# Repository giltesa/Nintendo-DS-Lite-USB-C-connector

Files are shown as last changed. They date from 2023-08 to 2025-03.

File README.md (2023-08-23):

# Nintendo DS Lite: USB-C connector

This is a special USB-C connector witch can be used to be directly soldered on the Nintendo DS Lite mainboard.

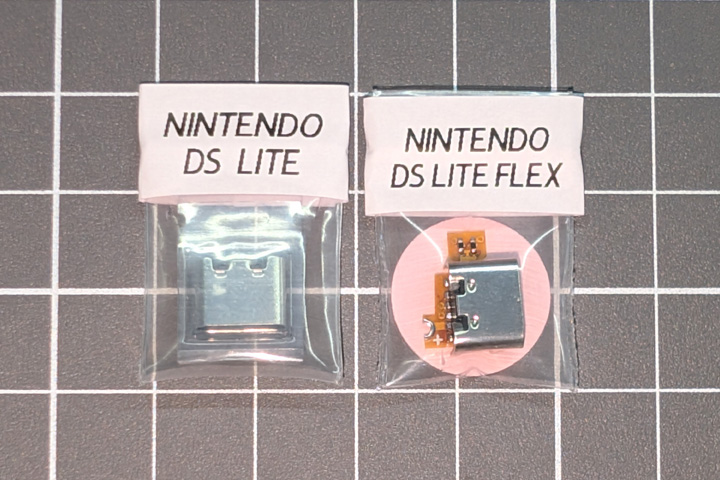
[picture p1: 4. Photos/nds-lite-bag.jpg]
Nintendo DS Lite: USB-C connector


## Note

This repo is only to host the PDF guide, there aren't design files.

## Would you like it?

[Nintendo DS Lite: USB-C connector](https://shop.giltesa.com/product/nintendo-ds-lite-usb-c-connector/)

## More

- [giltesa.com](https://giltesa.com "giltesa.com")
- [twitter.com](https://twitter.com/giltesa "twitter.com")

## License

This project is licensed under a **Creative Commons** license:
**[Attribution-NonCommercial-ShareAlike 4.0 International (CC BY-NC-SA 4.0) ](https://creativecommons.org/licenses/by-nc-sa/4.0/)**

Check the [LICENSE.md](LICENSE.md) for more information.

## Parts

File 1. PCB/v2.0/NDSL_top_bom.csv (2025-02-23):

Comment | Designator | Footprint | LCSC Part #
5.1K | R1 R2 | R0402 | C25905
USBC | J1 | USB-C_6P_SMD_NDSL | C668623

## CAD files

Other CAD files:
2. Renders, 3D models/NDS-LITE-FLEX.skp

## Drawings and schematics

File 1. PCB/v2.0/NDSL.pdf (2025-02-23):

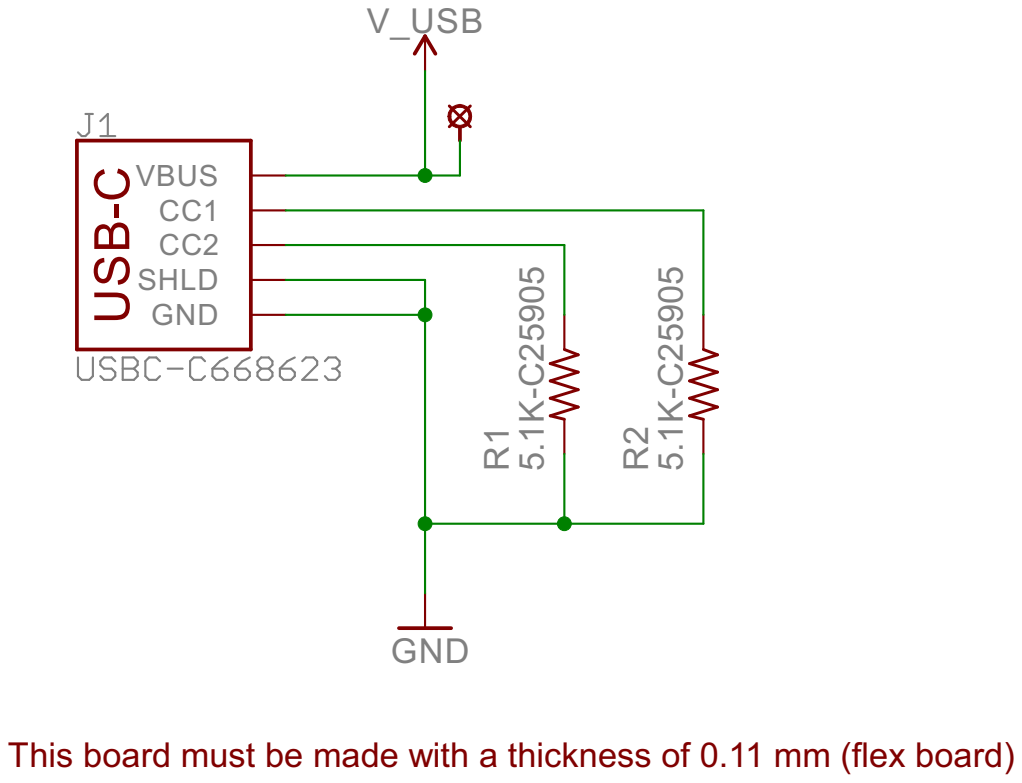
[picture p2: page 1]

This board must be made with a thickness of 0.11 mm (flex board)

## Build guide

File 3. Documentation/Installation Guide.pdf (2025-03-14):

# USB-C MOD for Nintendo DS Lite

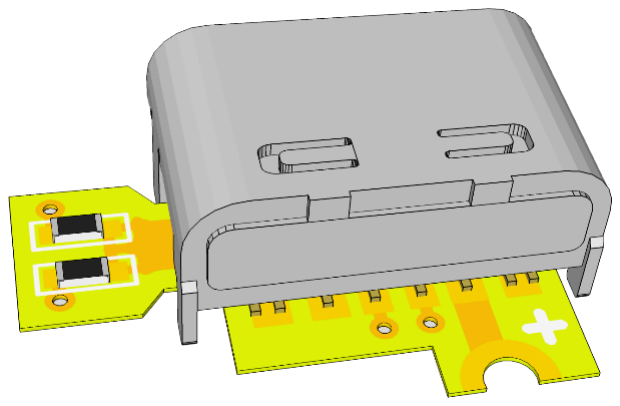
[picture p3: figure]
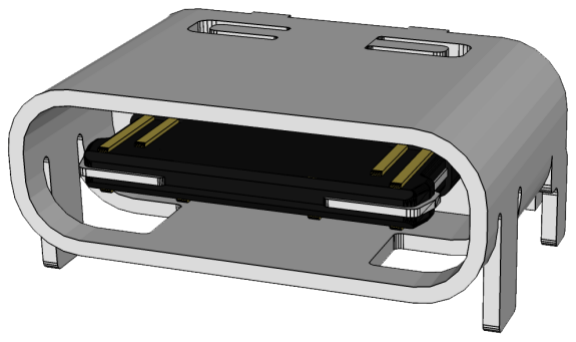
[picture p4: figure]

Connector version | board version

### PRODUCT

HTTPS://SHOP.GILTESA.COM/PRODUCT/NINTENDO-DS-LITE-USB-C-CONNECTOR HTTPS://SHOP.GILTESA.COM/PRODUCT/NINTENDO-DS-LITE-USB-C-KIT

# PLEASE READ THROUGH THESE INSTRUCTIONS

ENTIRELY BEFORE ATTEMPTING TO INSTALL.

# WARNING: IF YOU ARE NOT COMFORTABLE WITH SOLDERING, OR PERFORMING ANY STEP IN THIS

GUIDE, DO NOT PERFORM THE INSTALL YOURSELF.

# FIND SOMEONE WHO IS COMFORTABLE TO DO IT FOR

YOU.

INDEX

# Description

This product is a special USB-C connector which can be used to be directly soldered on the Nintendo DS Lite mainboard.

# FEATURES

- The USB-C connector match 100% perfect with the original connector shape and legs polarity.
- Charging your Nintendo DS Lite with:
- USB power banks
- USB-A chargers
- USB-C chargers*
- USB-C PD chargers (normal speed, not fast)*
- USB-A to USB-C cables
- USB-C to USB-C cables*

* Only the board version.

# INCLUDED

- USB-C connector or USB-C board (depending on the version you chose)

# Recommended / REQUIRED (NOT INCLUDED)

- Tri-wing and Phillips screwdriver
- Soldering iron
- Tin
- Desoldering pump
- Desoldering mesh
- Isopropyl alcohol

# NOTES

The connector version is not compatible with USB-C to USB-C cables; only standard USB to USB-C cables work.

The board version, however, is compatible with any cable or charger.

# Test the board!

Before starting the installation, you should test the board. If it doesn’t work contact me for a replacement (https://shop.giltesa.com/refund-policy/) (all boards are fully tested, but they may damage during the shipping, we try to package them as better as possible), if it works, go ahead with the installation.

Connect the power from your USB charger to the USB-C connector on the board. Then, with a multimeter in voltage measurement mode, check for a 5V reading. If that's the case, continue with the installation.

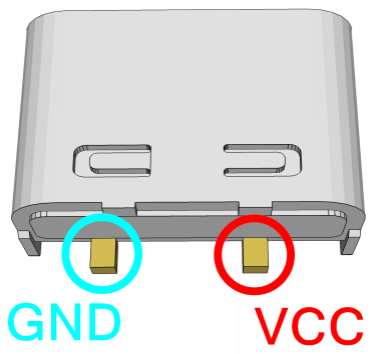
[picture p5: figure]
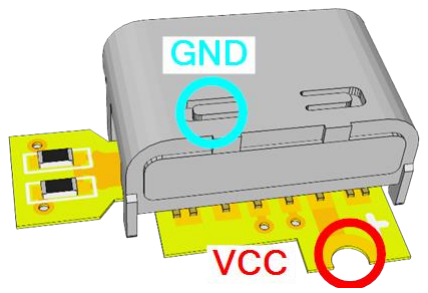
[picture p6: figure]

# INSTALLATION STEPS

## Pre installation Steps

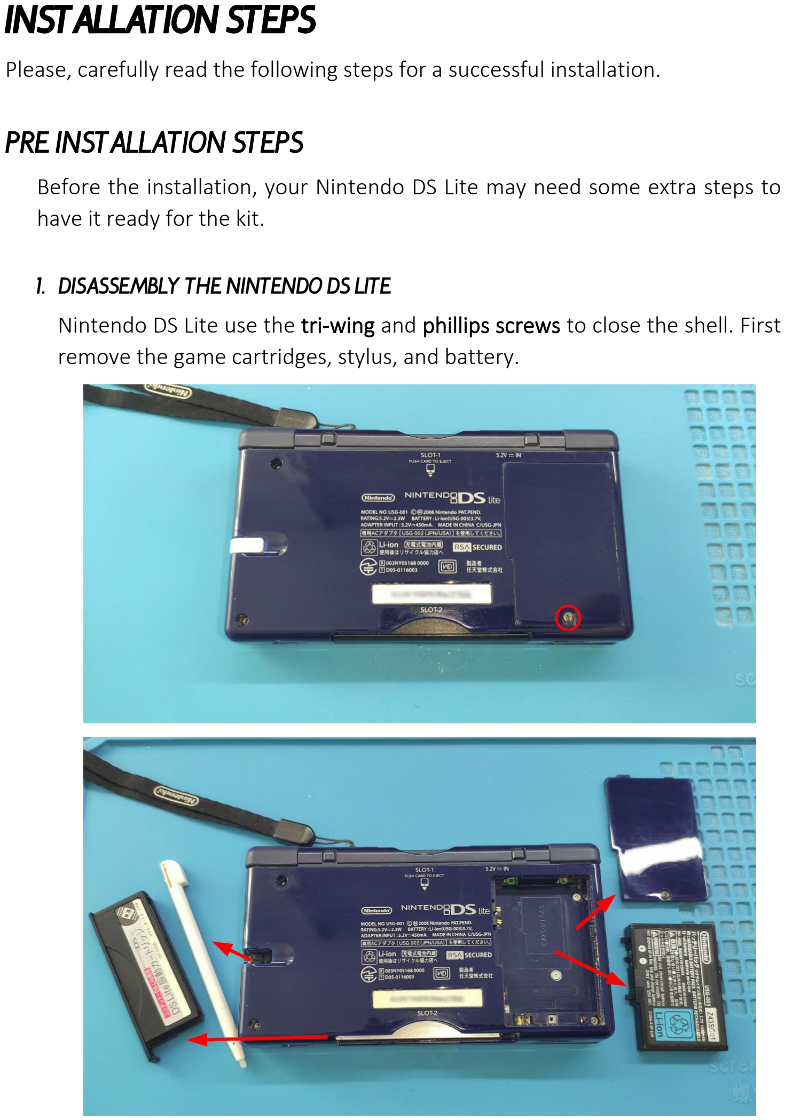
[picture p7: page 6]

Please, carefully read the following steps for a successful installation.

Before the installation, your Nintendo DS Lite may need some extra steps to have it ready for the kit.

1. Disassembly the Nintendo DS Lite

Nintendo DS Lite use the tri-wing and phillips screws to close the shell. First remove the game cartridges, stylus, and battery.

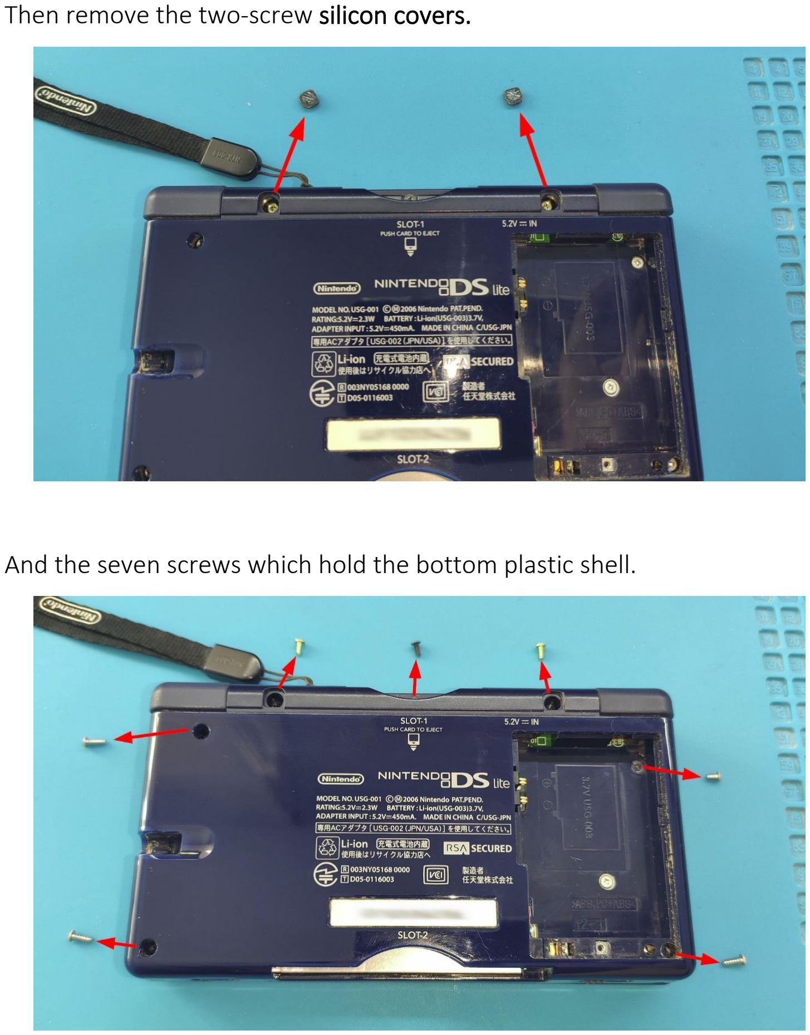
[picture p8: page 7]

Then remove the two-screw silicon covers.

And the seven screws which hold the bottom plastic shell.

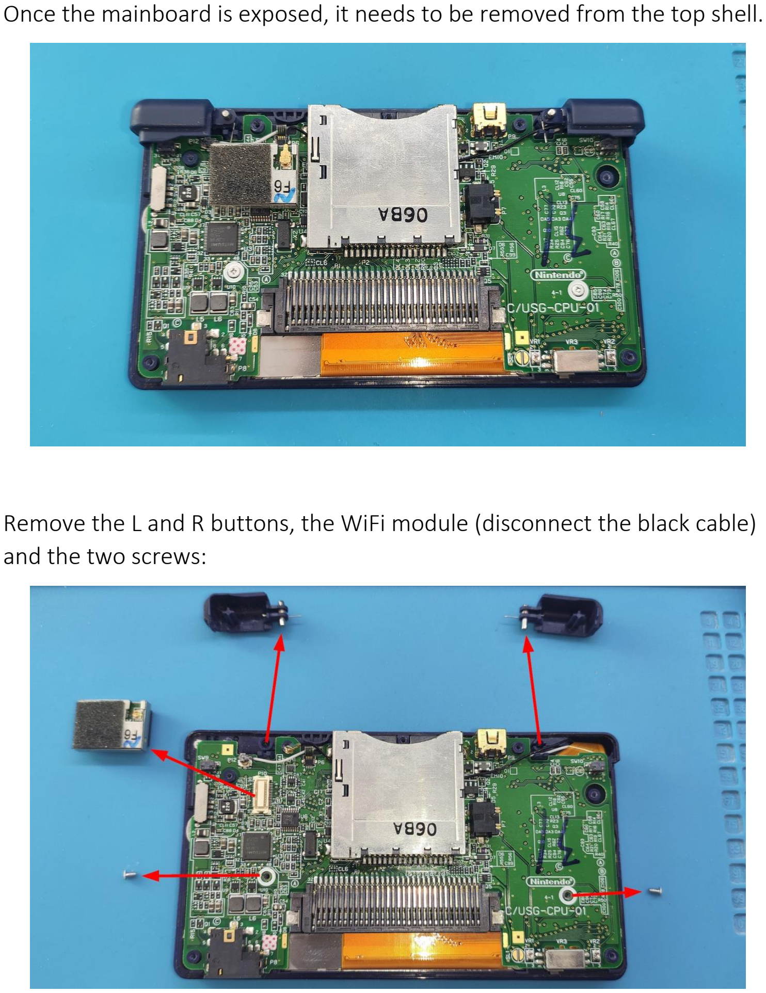
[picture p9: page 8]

Once the mainboard is exposed, it needs to be removed from the top shell.

Remove the L and R buttons, the WiFi module (disconnect the black cable) and the two screws:

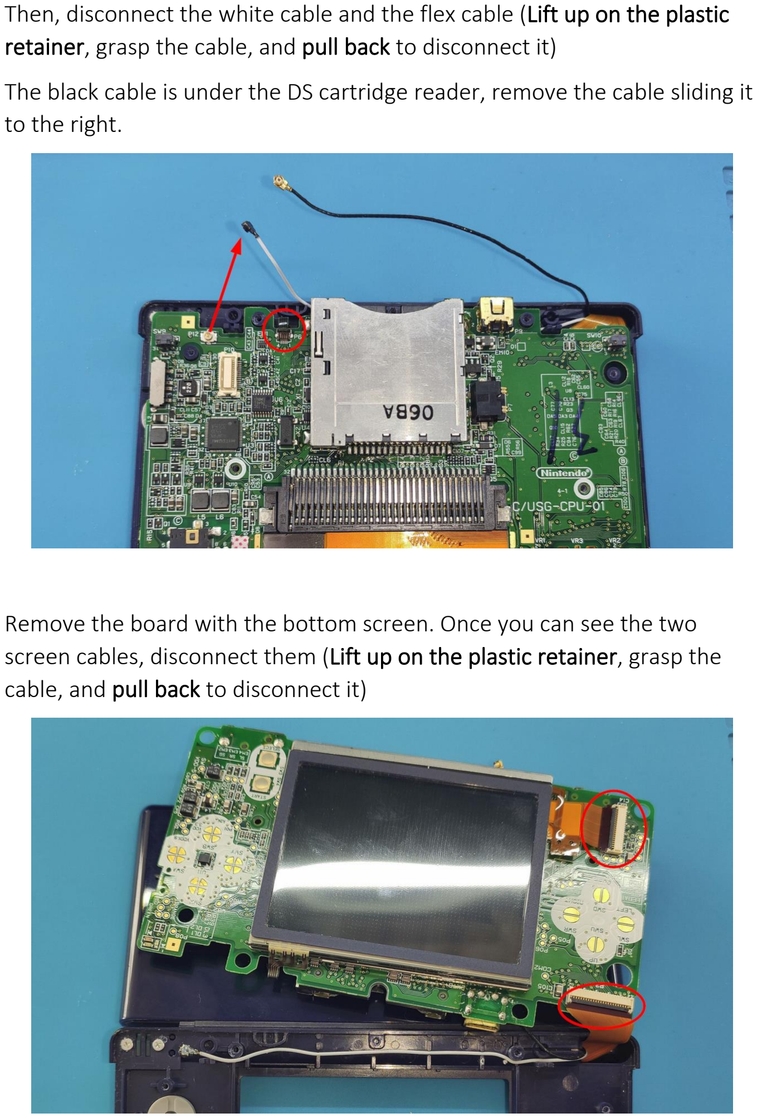
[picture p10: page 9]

Then, disconnect the white cable and the flex cable (Lift up on the plastic retainer, grasp the cable, and pull back to disconnect it)

The black cable is under the DS cartridge reader, remove the cable sliding it to the right.

Remove the board with the bottom screen. Once you can see the two screen cables, disconnect them (Lift up on the plastic retainer, grasp the cable, and pull back to disconnect it)

## installation Steps

1. Protect the nearest components

Use Kapton tape to protect and avoid any damage to the electronic components that are next to the connector.

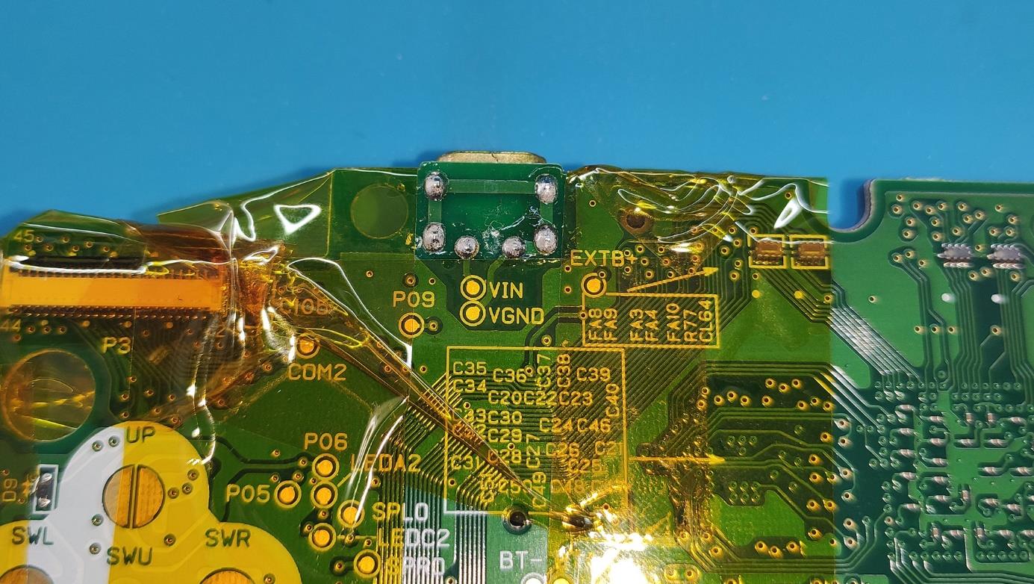
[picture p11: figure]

2. Remove unnecessary components

This installation only requires removing the power connector. However, it has many legs, and it may be hard to remove.

If you have an air solder station, you can remove it easily, but protect perfect the nearest places with Kapton tape or something may be burn.

Otherwise, the recommendation is using a desoldering pump which will help to remove the tin from each hole/pad.

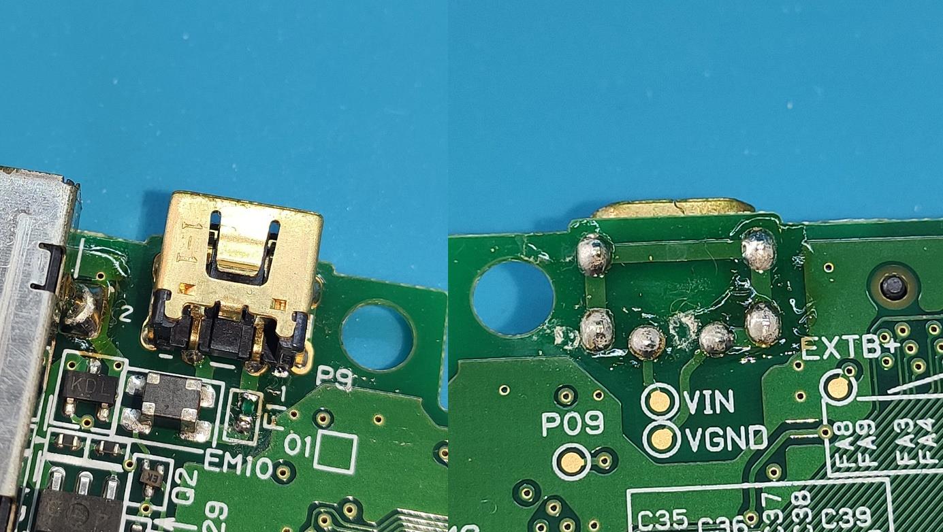
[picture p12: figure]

Start removing the tin from the VIN leg, which is easier. Then continue with the VGND leg which is connected also to the 4 connector shield legs. If you heat enough the 5 legs will melt at the same time and then the connector will move down.

3. Clean the board

After the component is removed, it may be dirty, clean both sides.

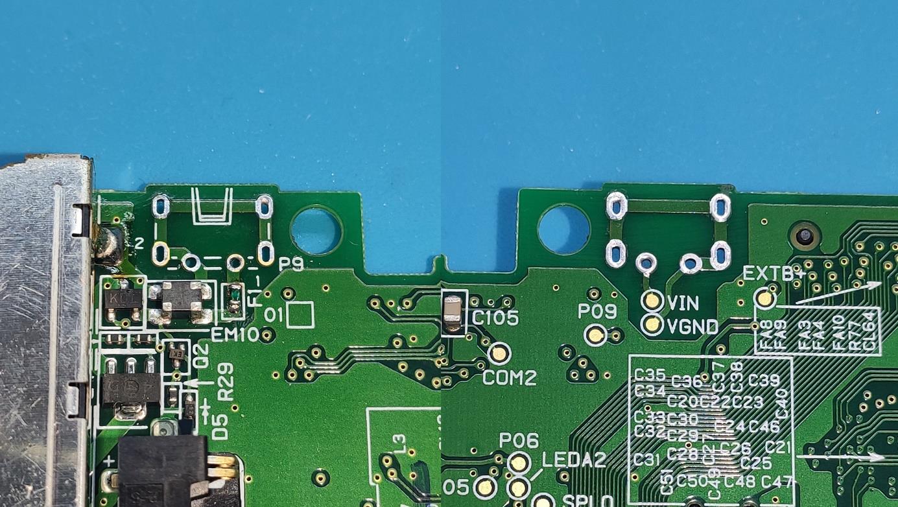
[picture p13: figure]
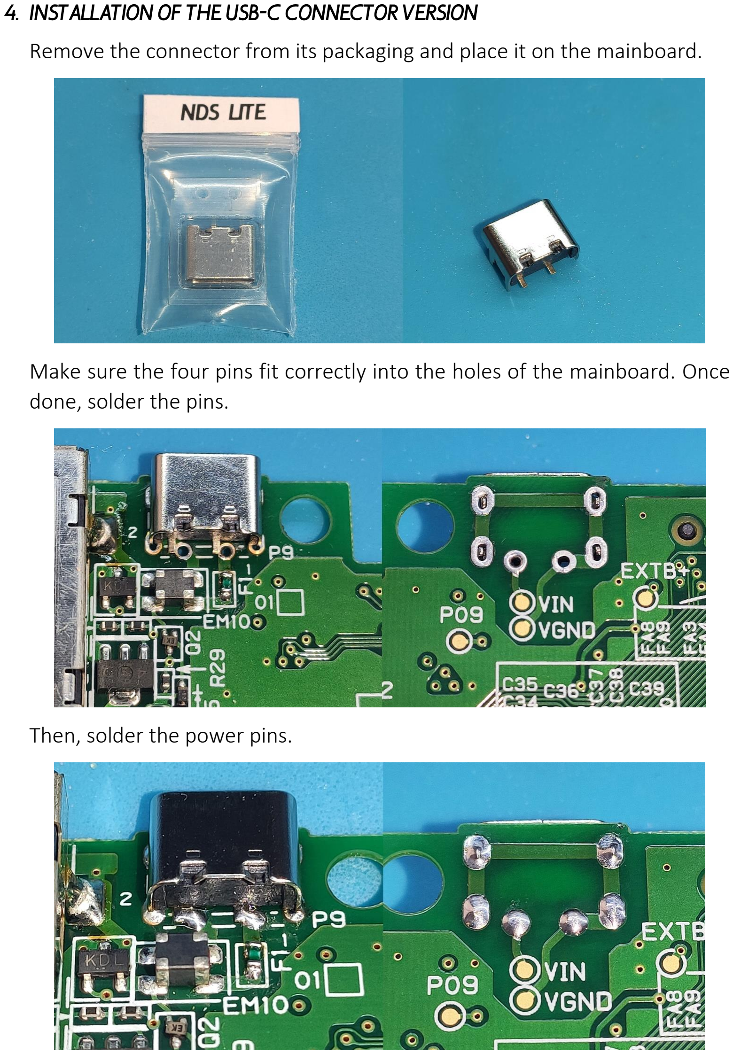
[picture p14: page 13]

4. Installation of the USB-C CONNECTOR VERSION

Remove the connector from its packaging and place it on the mainboard.

Make sure the four pins fit correctly into the holes of the mainboard. Once done, solder the pins.

Then, solder the power pins.

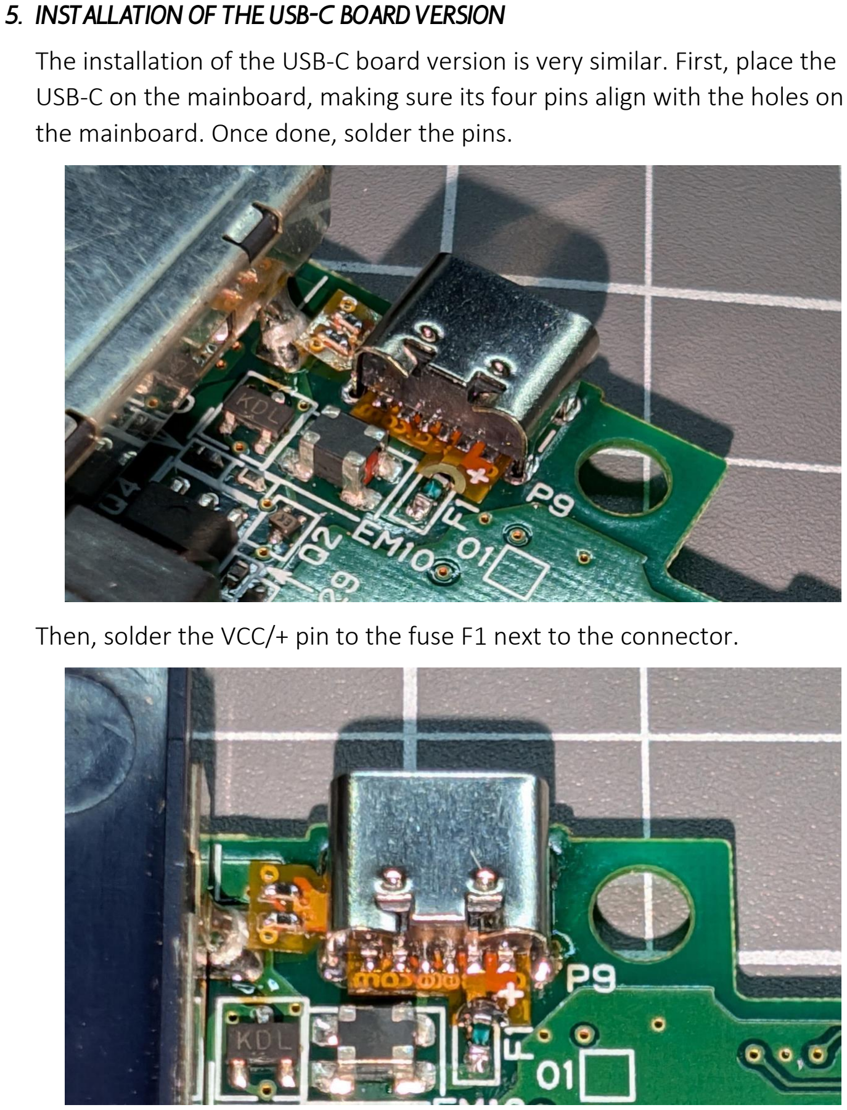
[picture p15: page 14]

5. Installation of the USB-C board VERSION

The installation of the USB-C board version is very similar. First, place the USB-C on the mainboard, making sure its four pins align with the holes on the mainboard. Once done, solder the pins.

Then, solder the VCC/+ pin to the fuse F1 next to the connector.

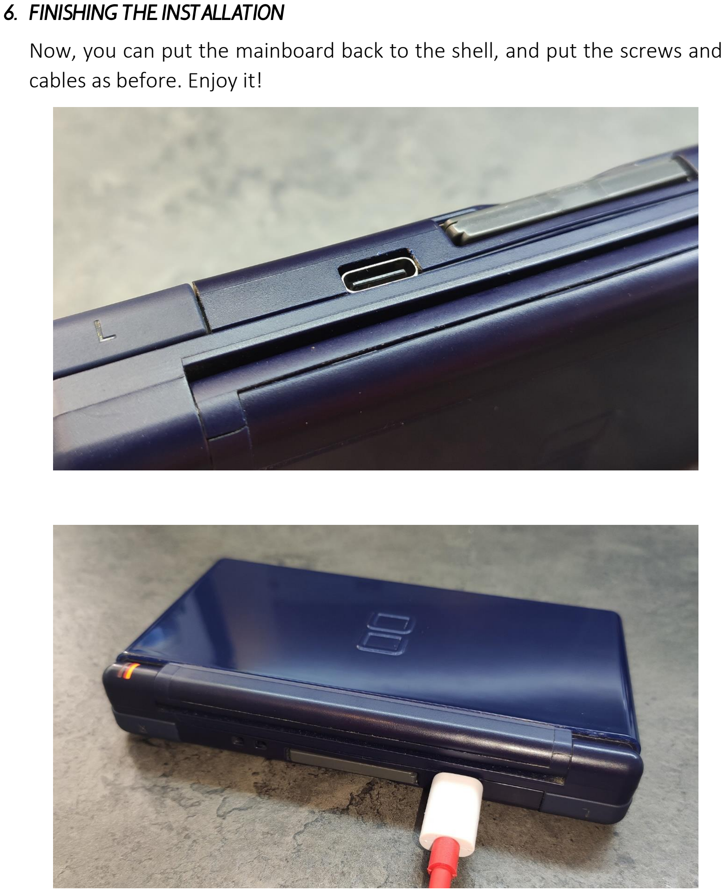
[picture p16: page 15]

6. Finishing the installation

Now, you can put the mainboard back to the shell, and put the screws and cables as before. Enjoy it!

# Frequently Asked Questions - FAQ

What charger can be used?
Connector version:

You need to use any USB charger with a USB connector and a USB-to-USB-C cable.

Board version:

You can use any standard charger for mobile phones, computers, etc., with 5V 1A. It doesn't need to be a Power Delivery charger since this feature is not used. Of course, if you want to use a Power Delivery charger, there's no problem or risk.

Technical data for curious minds:

Power Delivery chargers can supply a wide range of voltages: 5V, 9V, 12V, 15V, and 20V. However, for this to happen, the device must communicate with the charger to explicitly request the desired voltage. Without this communication, the charger will never supply more than 5V. That's one of the advantages of USB-C, as it can be used with both old and modern devices.
